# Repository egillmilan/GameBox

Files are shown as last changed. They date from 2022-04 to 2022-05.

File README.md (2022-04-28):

# GameBox
Battery powered pocket device for playing games on. Based on the ATmega328P microcontroller from Atmel, same as is used in the Arduino Uno. Fits in a Hammond 1551k case.

GameBox_v3_1
GameBox_v3_2
GameBox_v3_3
GameBox_v3_4

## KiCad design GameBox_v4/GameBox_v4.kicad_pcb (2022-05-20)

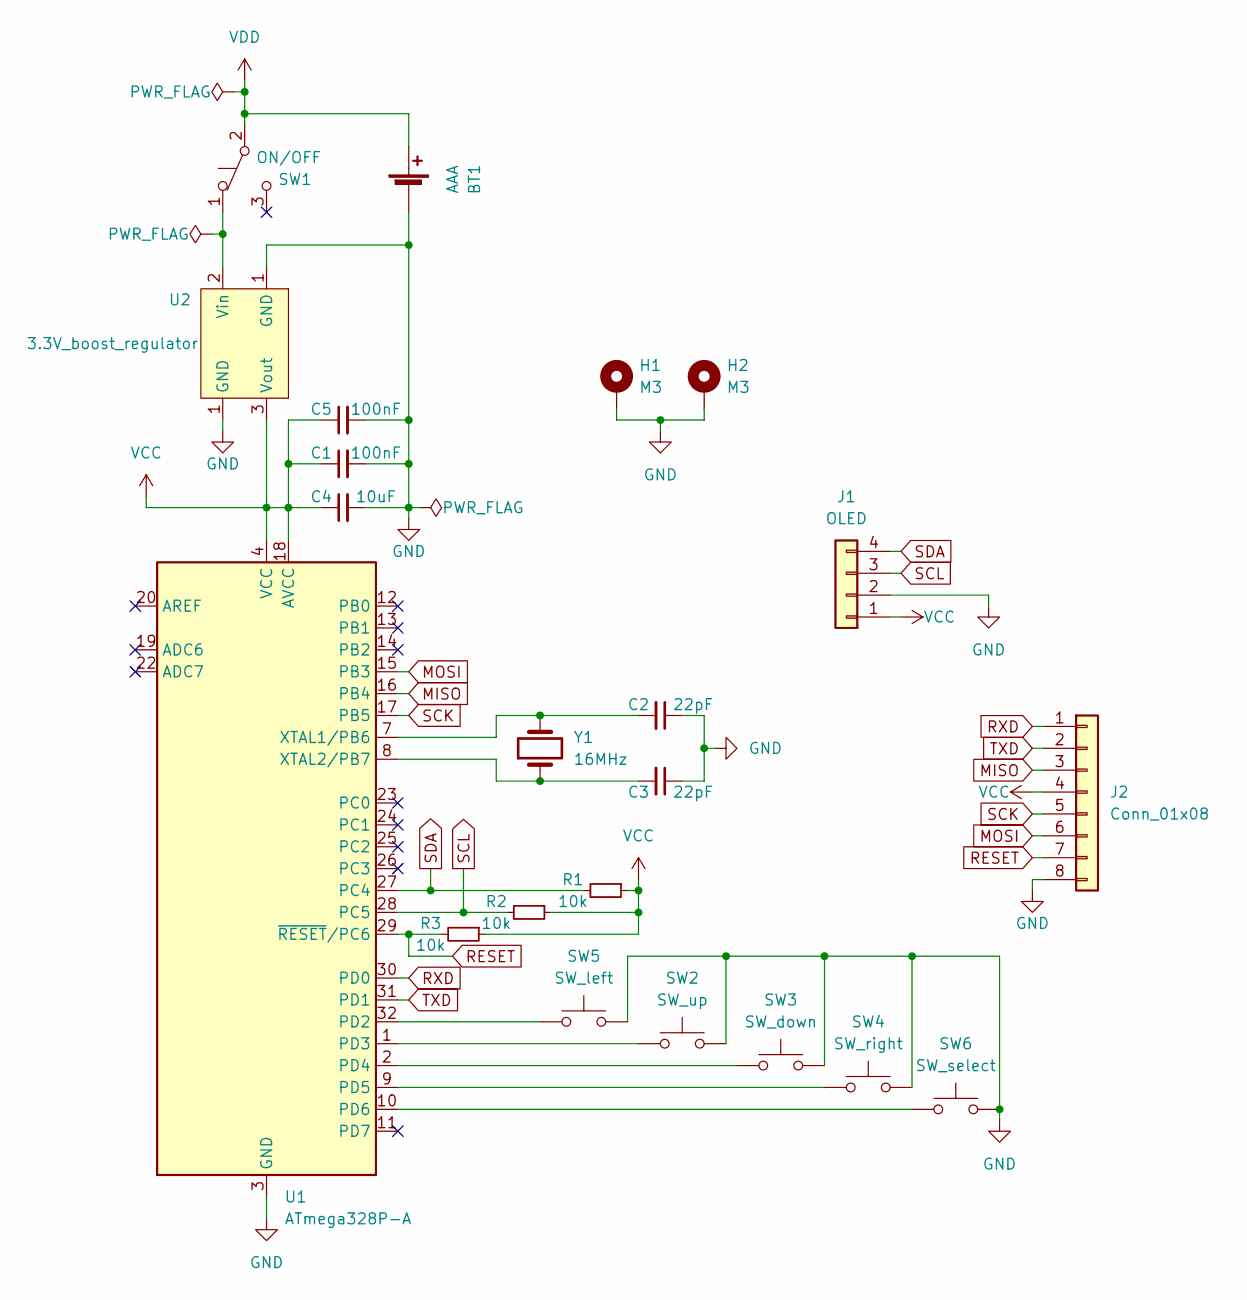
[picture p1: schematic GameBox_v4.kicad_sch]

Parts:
BT1: AAA; BK-82_AAA_battery_holder
C1, C5: 100nF; C_0805_2012Metric_Pad1.18x1.45mm_HandSolder
C2, C3: 22pF; C_0805_2012Metric_Pad1.18x1.45mm_HandSolder
C4: 10uF; C_0805_2012Metric_Pad1.18x1.45mm_HandSolder
H1, H2: M3; MountingHole_3.2mm_M3_Pad_Via
J1: OLED; 1.3_inch_OLED_IIC
J2: Conn_01x08; PinHeader_2x04_P2.54mm_Vertical
R1, R2, R3: 10k; R_0805_2012Metric_Pad1.20x1.40mm_HandSolder
SW1: ON/OFF; SS12D10
SW2: SW_up; SW_PUSH_6mm_H9.5mm
SW3: SW_down; SW_PUSH_6mm_H9.5mm
SW4: SW_right; SW_PUSH_6mm_H9.5mm
SW5: SW_left; SW_PUSH_6mm_H9.5mm
SW6: SW_select; SW_PUSH_6mm_H9.5mm
U1: ATmega328P-A; TQFP-32_7x7mm_P0.8mm
U2: 3.3V_boost_regulator; 3.3V_boost_regulator_castellated
Y1: 16MHz; Crystal_HC49-4H_Vertical

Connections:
GND: BT1.2 (-), C1.2, C2.1, C3.1, C4.2, C5.2, H1.1, H2.1, J1.2, J2.8, SW2.2, SW3.2, SW4.2, SW5.2, SW6.2, U1.3 (GND), U1.5 (GND), U1.21 (GND), U2.1 (GND)
MISO: J2.3, U1.16 (PB4)
MOSI: J2.6, U1.15 (PB3)
unnamed: C2.2, U1.7 (XTAL1/PB6), Y1.2
unnamed: C3.2, U1.8 (XTAL2/PB7), Y1.1
unnamed: SW1.1 (A), U2.2 (Vin)
unnamed: SW2.1, U1.1 (PD3)
unnamed: SW3.1, U1.2 (PD4)
unnamed: SW4.1, U1.9 (PD5)
unnamed: SW5.1, U1.32 (PD2)
unnamed: SW6.1, U1.10 (PD6)
RESET: J2.7, R3.2, U1.29 (~RESET/PC6)
RXD: J2.1, U1.30 (PD0)
SCK: J2.5, U1.17 (PB5)
SCL: J1.3, R2.2, U1.28 (PC5)
SDA: J1.4, R1.2, U1.27 (PC4)
TXD: J2.2, U1.31 (PD1)
VCC: C1.1, C4.1, C5.1, J1.1, J2.4, R1.1, R2.1, R3.1, U1.4 (VCC), U1.6 (VCC), U1.18 (AVCC), U2.3 (Vout)
VDD: BT1.1 (+), SW1.2 (B)

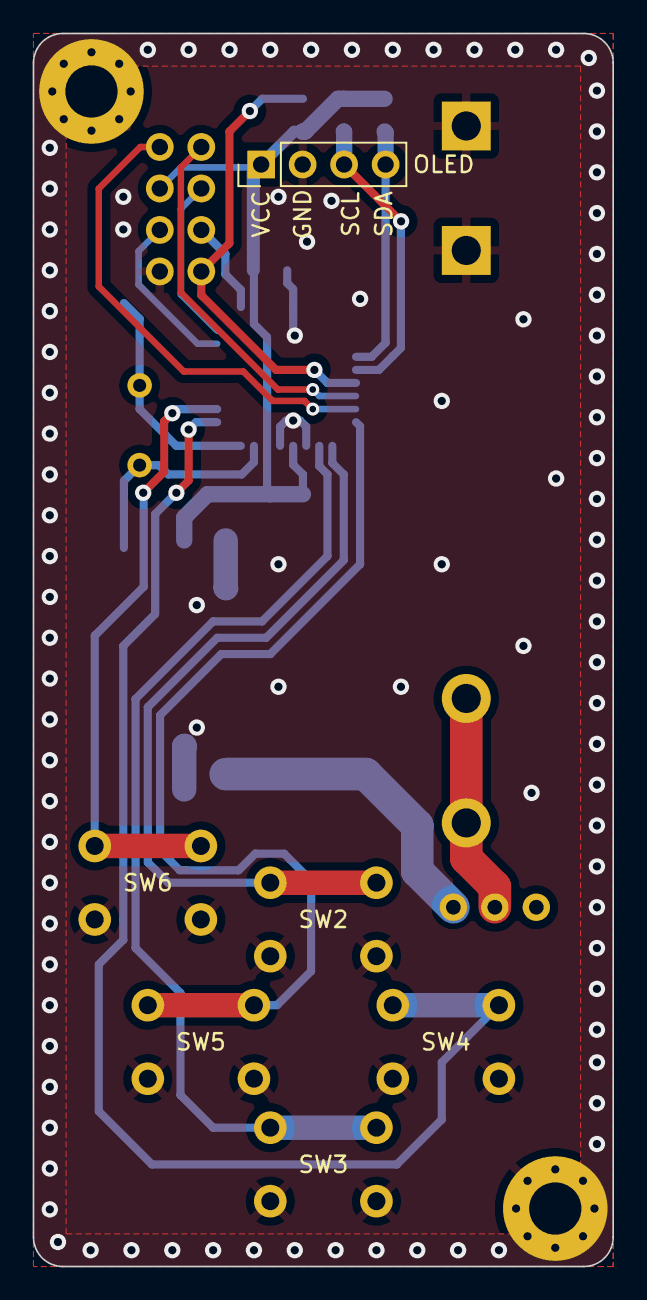
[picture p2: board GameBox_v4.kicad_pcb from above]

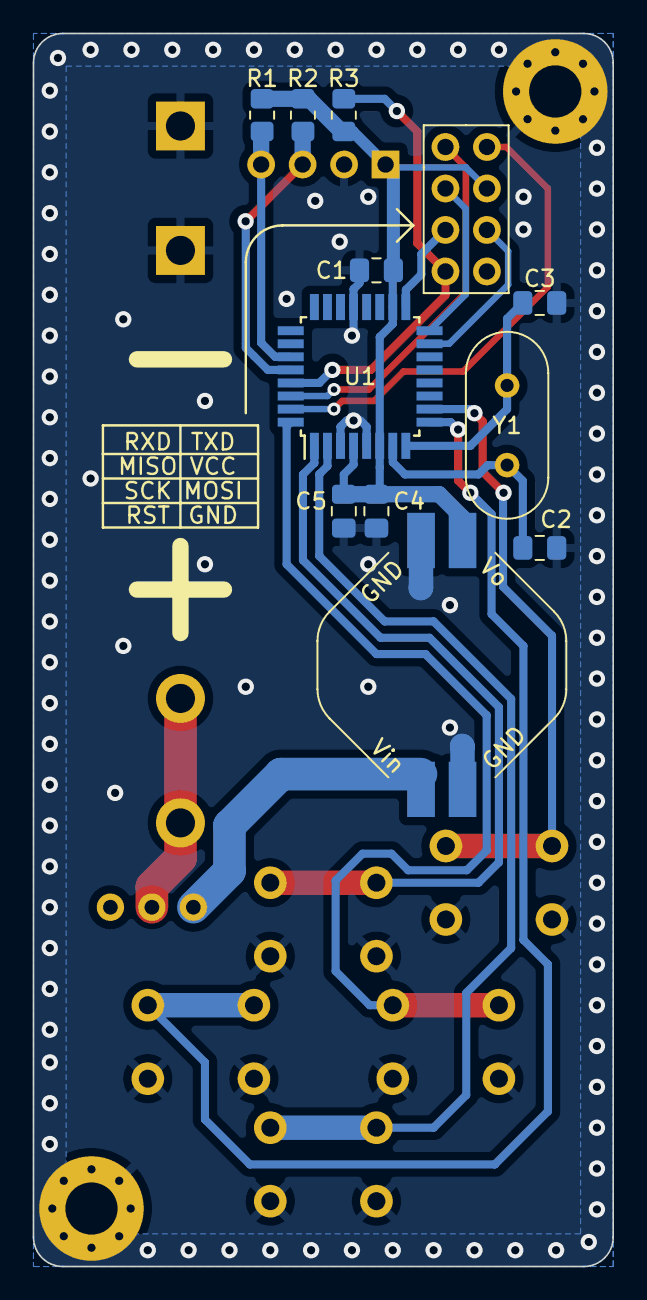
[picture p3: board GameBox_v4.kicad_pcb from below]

Board: 2 copper layers, 35.5 x 75.5 mm, 22 parts (13 on the bottom side), 19 nets.

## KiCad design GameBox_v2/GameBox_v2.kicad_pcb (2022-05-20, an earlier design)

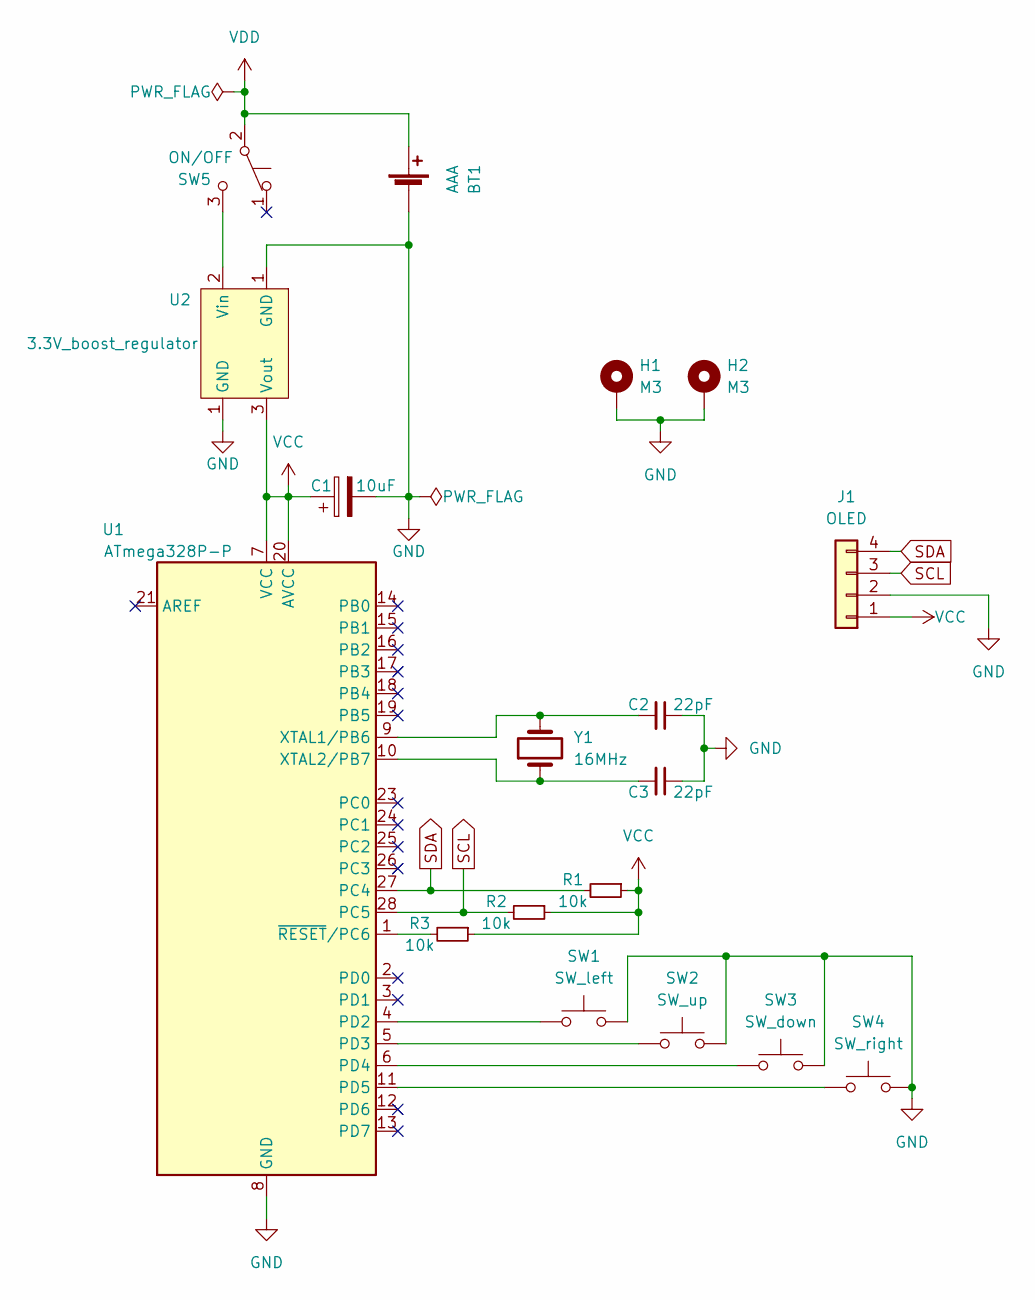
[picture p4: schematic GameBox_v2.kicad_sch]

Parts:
BT1: AAA; BK-82_AAA_battery_holder
C1: 10uF; C_0805_2012Metric_Pad1.18x1.45mm_HandSolder
C2, C3: 22pF; C_0805_2012Metric_Pad1.18x1.45mm_HandSolder
H1, H2: M3; MountingHole_3.2mm_M3_Pad_Via
J1: OLED; 1.3_inch_OLED_IIC
R1, R2, R3: 10k; R_0805_2012Metric_Pad1.20x1.40mm_HandSolder
SW1: SW_left; SW_PUSH_6mm_H9.5mm
SW2: SW_up; SW_PUSH_6mm_H9.5mm
SW3: SW_down; SW_PUSH_6mm_H9.5mm
SW4: SW_right; SW_PUSH_6mm_H9.5mm
SW5: ON/OFF; EG1218
U1: ATmega328P-P; DIP-28_W7.62mm
U2: 3.3V_boost_regulator
Y1: 16MHz; Crystal_HC49-4H_Vertical

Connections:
GND: BT1.2 (-), C1.2, C2.1, C3.1, H1.1, H2.1, J1.2, SW1.2, SW2.2, SW3.2, SW4.2, U1.8 (GND), U1.22 (GND), U2.1 (GND)
unnamed: C2.2, U1.9 (XTAL1/PB6), Y1.2
unnamed: C3.2, U1.10 (XTAL2/PB7), Y1.1
unnamed: R3.2, U1.1 (~RESET/PC6)
unnamed: SW1.1, U1.4 (PD2)
unnamed: SW2.1, U1.5 (PD3)
unnamed: SW3.1, U1.6 (PD4)
unnamed: SW4.1, U1.11 (PD5)
unnamed: SW5.3 (C), U2.2 (Vin)
SCL: J1.3, R2.2, U1.28 (PC5)
SDA: J1.4, R1.2, U1.27 (PC4)
VCC: C1.1, J1.1, R1.1, R2.1, R3.1, U1.7 (VCC), U1.20 (AVCC), U2.3 (Vout)
VDD: BT1.1 (+), SW5.2 (B)

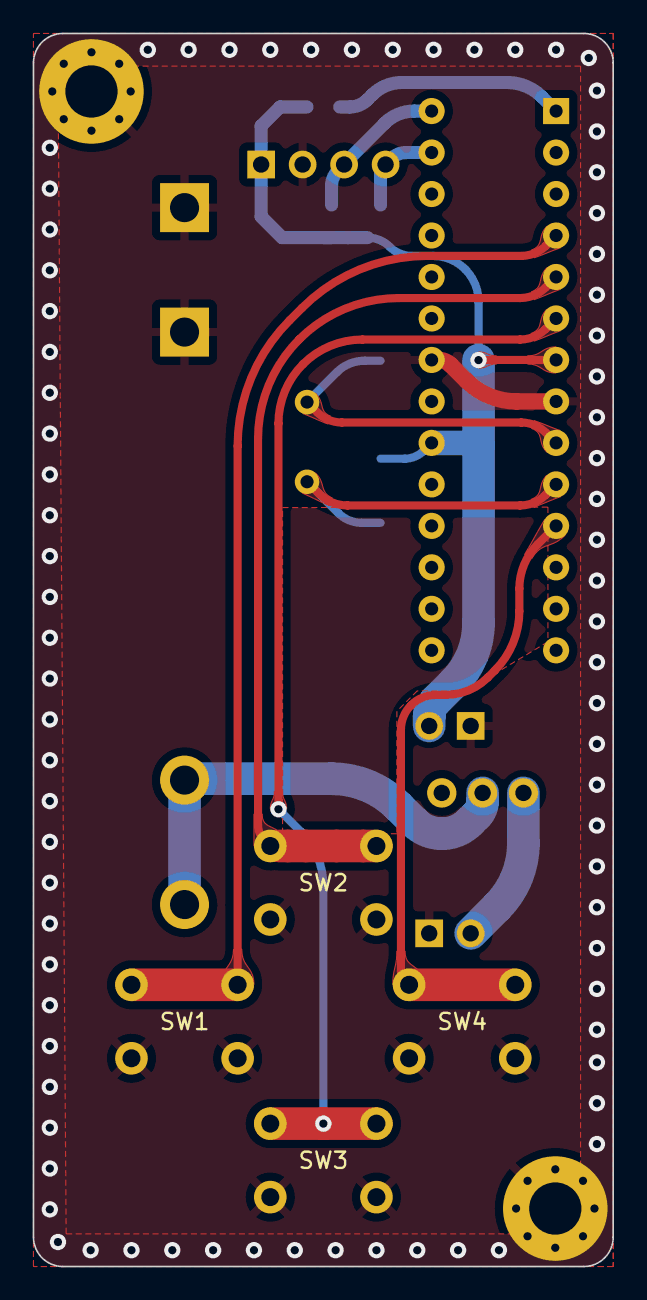
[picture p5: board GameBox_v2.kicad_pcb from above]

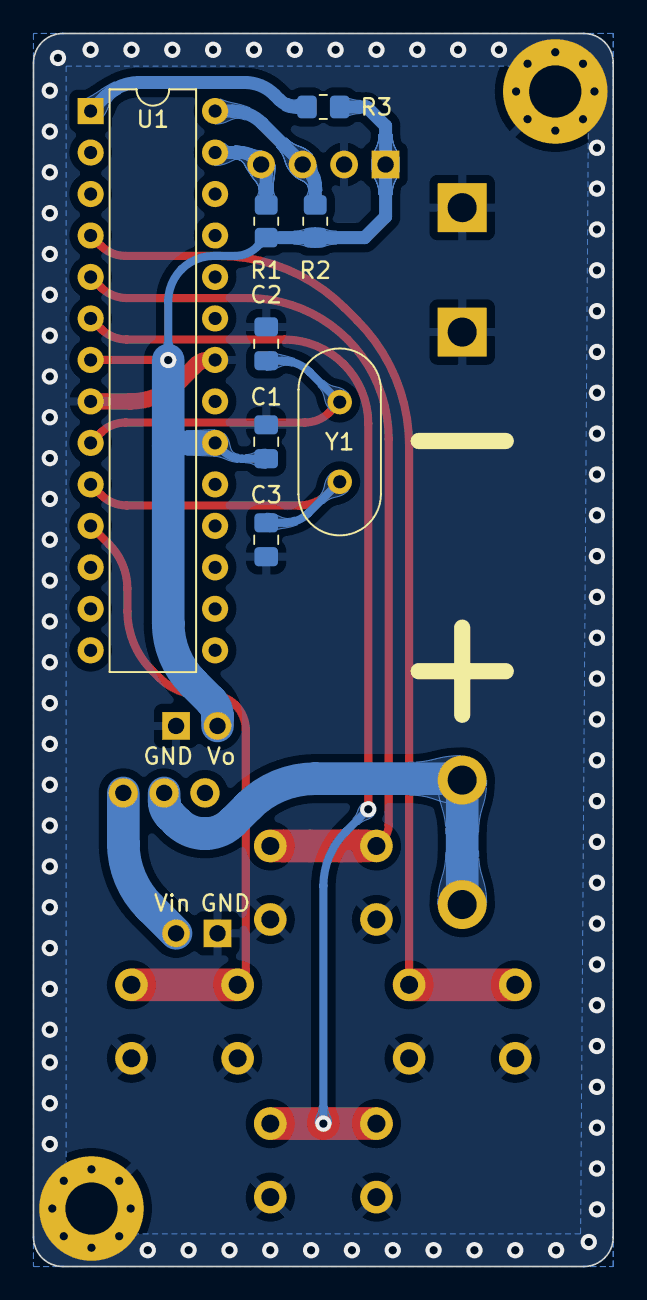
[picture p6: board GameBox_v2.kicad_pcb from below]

Board: 2 copper layers, 35.5 x 75.5 mm, 18 parts (10 on the bottom side), 13 nets.

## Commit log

2022-04-01 Component placement
    [GameBox.kicad_pcb, GameBox.kicad_sch]
2022-04-02 Finished PCB design
    Finished PCB design and schematic
    [GameBox.kicad_pcb, GameBox.kicad_sch, GameBox_v1.kicad_pcb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]
2022-04-04 Version 2 designed
    Version 2 uses a single cell and a boost converter. Version 2 uses a few SMD components in order to reduce the clutter on the PCB and the SPI bus was ditched in V2 as well.
    [GameBox_v2.kicad_pcb, GameBox_v2.kicad_sch]
2022-04-11 Version 3 added and minor fixes to v2
    [GameBox_v3.kicad_pcb, GameBox_v3.kicad_sch]
2022-04-16 Added v4
    v4 supports the castellated version of the 3.3V boost regulator for a slightly cleaner PCB with more surface mounted components
    [GameBox_v4.kicad_pcb, GameBox_v4.kicad_sch]
2022-04-28 Rounded tracks and teardrops
    [GameBox_v2.kicad_pcb, GameBox_v2.kicad_sch]
2022-04-28 Footprint updates
    [GameBox_v2.kicad_pcb, GameBox_v2.kicad_sch]
2022-05-20 fixed OLEDs
    [GameBox_v2.kicad_pcb, GameBox_v2.kicad_sch, GameBox_v3.kicad_pcb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]
